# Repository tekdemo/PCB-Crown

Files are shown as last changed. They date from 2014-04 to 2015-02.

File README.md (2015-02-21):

PCB Crown
=========
A fun experiment in 3D circuits and wearables, designed as a gift to Laen. It was unveiled at the 2014 Maker Faire Bring-a-hack party. 

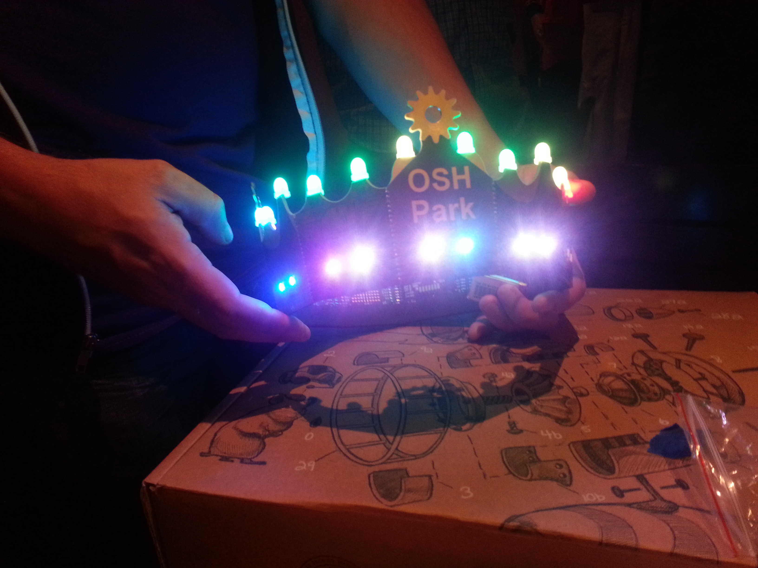
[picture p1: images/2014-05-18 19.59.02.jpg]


About The Crown
---------------
The structure of the crown is 11 different panels, held together via PCB Castellations and solder. The 11 panels are made from
5 different designs, and used 3 copies of the tall face plate, and 2 copies of each other design.

The electrical side of the crown is primarily configured to drive 2 individually addressable LED strings. There's a total of 44 RGB LEDs, configured as 2 strings of 22 each
The top uses [8mm Diffused LEDs](https://www.adafruit.com/products/1734), and the faces use [WS2812B SMD LEDs](https://www.adafruit.com/products/1655). These are 
powered by a [SMDuino module](https://code.google.com/p/smduino/), with optional buttons for whatever nefarious purpose seems desirable.

Each module also has a tiny circuit that acts as a SMD equivilent to a breadboard, suitable for future additions of accellerometers, gyros, or light sensors. 
Here's the crown glowing with the full might of the NeoPixels running Adafruit's test patterns. 

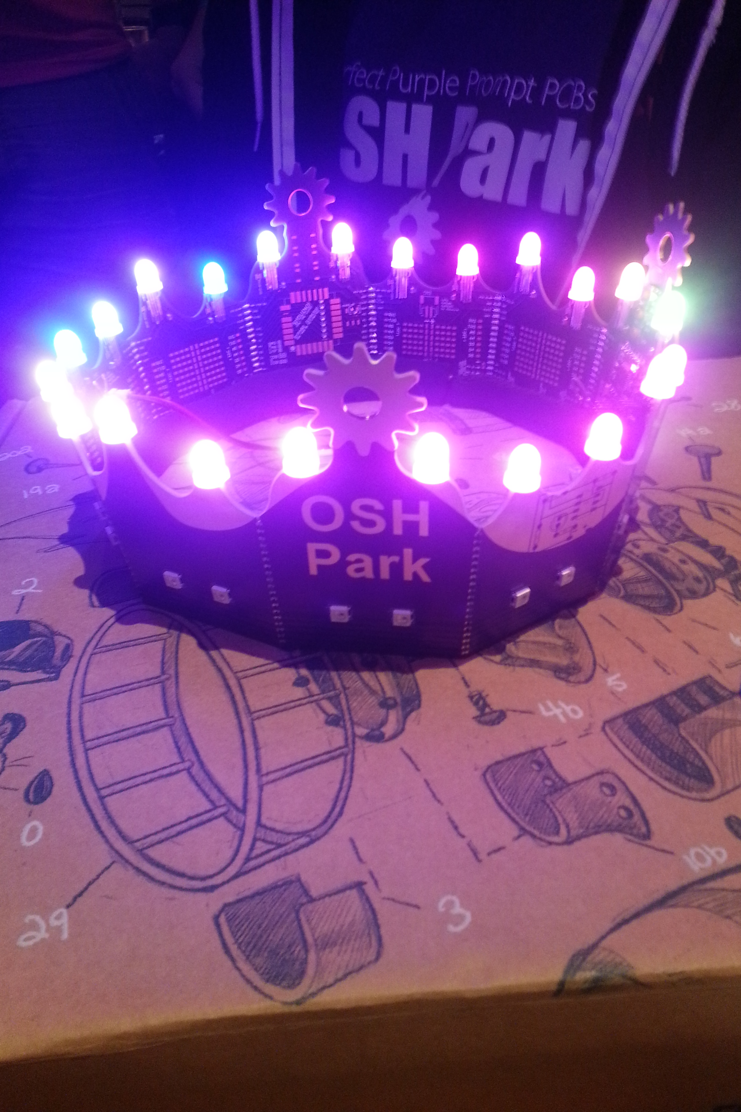
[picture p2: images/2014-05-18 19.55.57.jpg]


WARNING!
--------
This is being published as an demonstration and example project, not as a completed work suitable for replication. 
As an experimental design, this is _highly_ unlikely to work properly for you. The chosen board interconnects are incredibly fragile, and will often stop functioning
if bumped, jostled, or left alone quietly in a dark room. Several part footprints, due to artistic constraints, are maddening to assemble and virtually impossible to test effectively. 
No individual panel will work at all without the adjacent panel, requires at least 1 cut trace, and the LEDs will not work properly without at 
least half the design completed and working. 

Full documentation, build notes, and additional details are posted at [tekdemo.github.io/](https://tekdemo.github.io/pcb-crown/). This includes things not to do, as discovered
in the course of designing and building the crown.

License
--------
Files under `/images/` and the contents of the `gh-pages` branch are liscenced under [Creative Commons Attribution-ShareAlike 4.0](https://creativecommons.org/licenses/by-sa/4.0/)

All other files are released under the [MIT License](http://opensource.org/licenses/MIT).

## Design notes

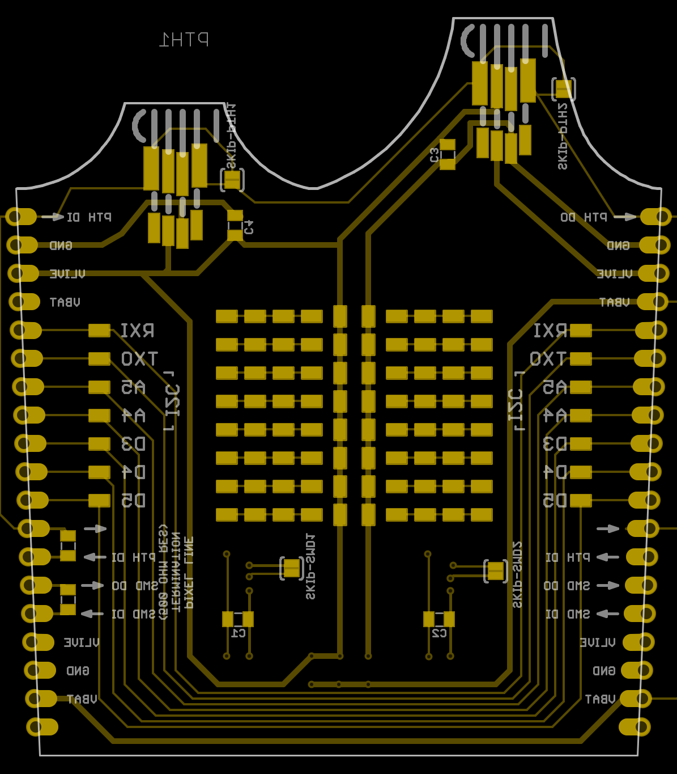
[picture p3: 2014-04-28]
gerber-previews/crown-C.board-bottom.png

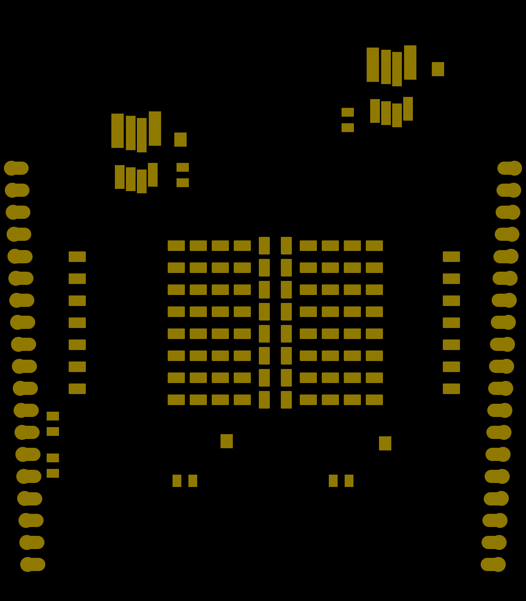
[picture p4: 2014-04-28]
gerber-previews/crown-C.bottomstopmask.png

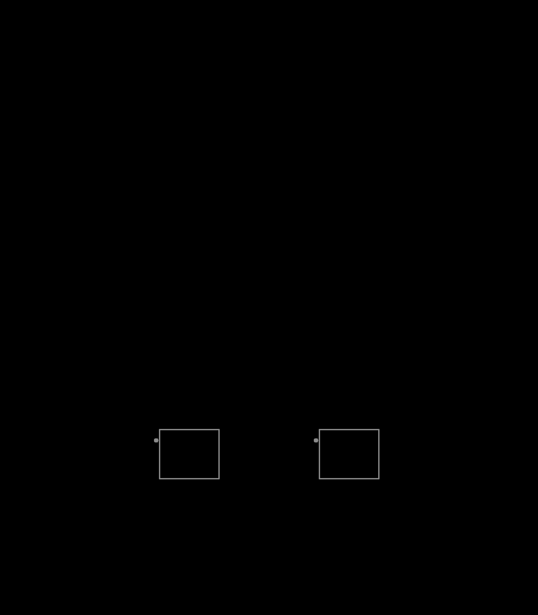
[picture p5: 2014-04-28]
gerber-previews/crown-F.topsilkscreen.png

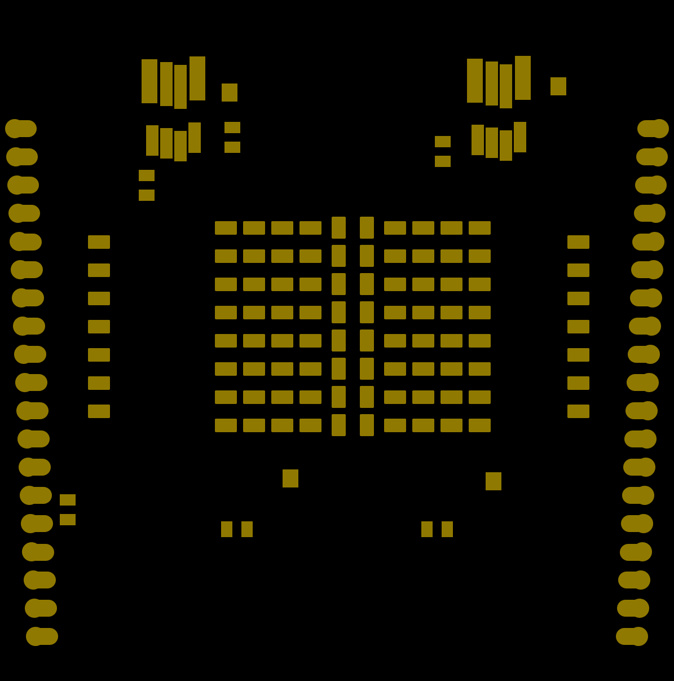
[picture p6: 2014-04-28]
gerber-previews/crown-E.bottomstopmask.diff.png

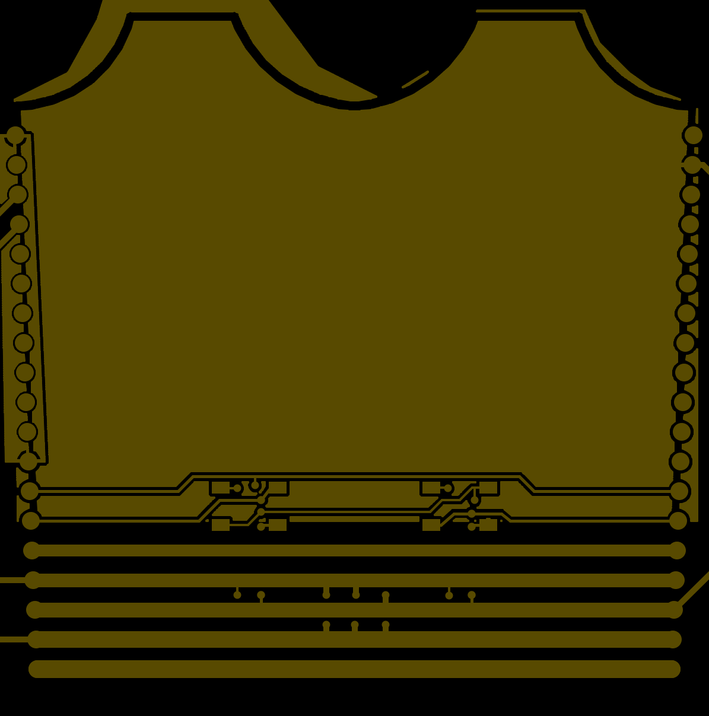
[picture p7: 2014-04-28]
gerber-previews/crown-E.toplayer.png

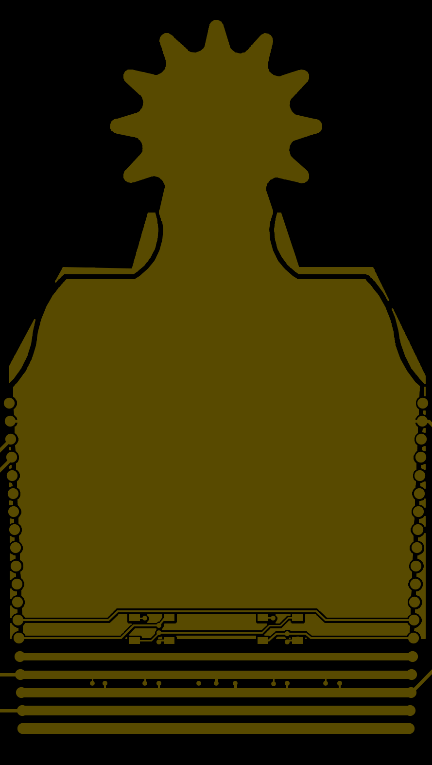
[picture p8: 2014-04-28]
gerber-previews/crown-face.toplayer.diff.png

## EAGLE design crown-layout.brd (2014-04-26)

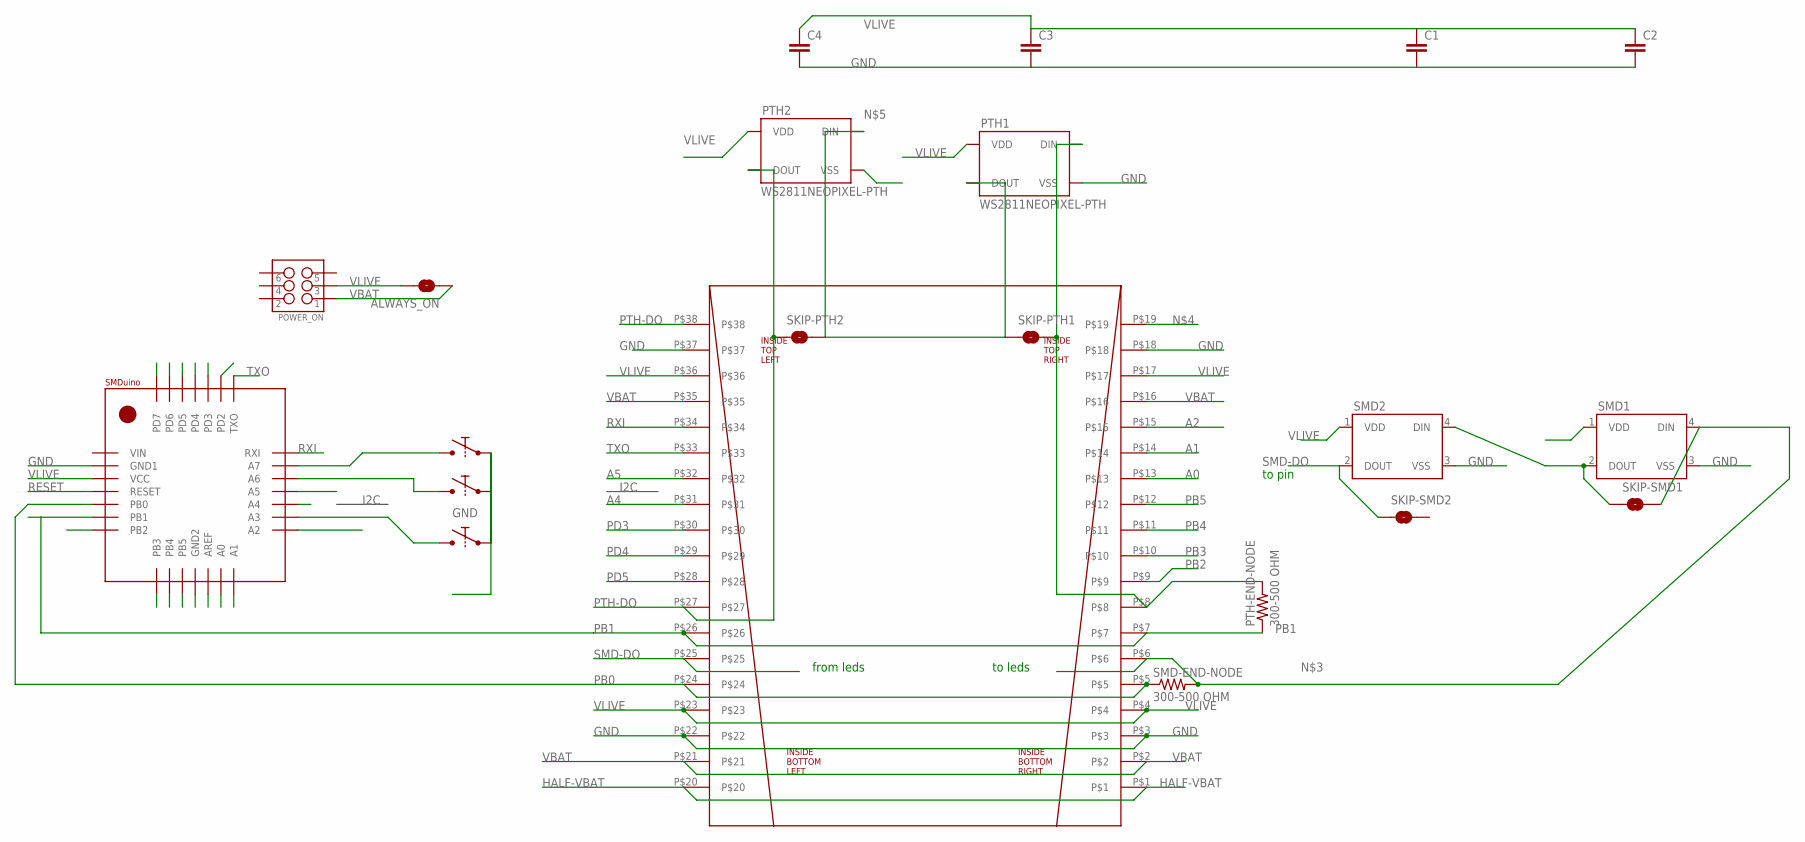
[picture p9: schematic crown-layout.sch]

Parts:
A6, A7: BUTTONSMD_BUTTON; SMD_BUTTON
ALWAYS_ON: SOLDERJUMPERNC2; SJ_2S-NOTRACE
C1, C2, C3, C4: CAP0805; 0805
D2: BUTTONSMD_BUTTON; SMD_BUTTON
POWER_ON: M03X2FEMALE_SMD; 2X3_SMD
PTH1, PTH2: WS2811NEOPIXEL-PTH; WS2811-PTH-FLAT
PTH-END-NODE: 300-500 OHM; 0805
SKIP-PTH1, SKIP-PTH2: SOLDERJUMPERNC2; SJ_2S-NOTRACE
SKIP-SMD1, SKIP-SMD2: SOLDERJUMPERNC2; SJ_2S-NOTRACE
SMD1, SMD2: WS2812B
SMD-END-NODE: 300-500 OHM; 0805
U$1: SMDUINO
U$2: CROWNSTANDARD; CROWN

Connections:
A0: U$1.A0, U$2.P$13
A1: U$1.A1, U$2.P$14
A2: U$1.A2, U$2.P$15
A3: A6.P$1, A6.P$2, U$1.A3
A4: U$1.A4, U$2.P$31
A5: U$1.A5, U$2.P$32
A6: A7.P$1, A7.P$2, U$1.A6
A7: D2.P$1, D2.P$2, U$1.A7
GND: A6.P$3, A6.P$4, A7.P$3, A7.P$4, C1.2, C2.2, C3.2, C4.2, D2.P$3, D2.P$4, PTH1.P$2 (VSS), PTH1.P$6 (VSS), PTH2.P$2 (VSS), PTH2.P$6 (VSS), SMD1.3 (VSS), SMD2.3 (VSS), U$1.GND1, U$2.P$3, U$2.P$18, U$2.P$22, U$2.P$37
HALF-VBAT: U$2.P$1, U$2.P$20
unnamed: SKIP-SMD1.2, SMD1.4 (DIN), SMD-END-NODE.2, U$2.P$6
unnamed: PTH1.P$4 (DIN), PTH1.P$8 (DIN), PTH-END-NODE.2, SKIP-PTH1.2, U$2.P$8, U$2.P$19
unnamed: PTH1.P$1 (DOUT), PTH1.P$5 (DOUT), PTH2.P$4 (DIN), PTH2.P$8 (DIN), SKIP-PTH1.1, SKIP-PTH2.2
unnamed: SKIP-SMD1.1, SMD1.2 (DOUT), SMD2.4 (DIN)
PB0: SMD-END-NODE.1, U$1.PB0, U$2.P$5, U$2.P$24
PB1: PTH-END-NODE.1, U$1.PB1, U$2.P$7, U$2.P$26
PB2: U$1.PB2, U$2.P$9
PB3: U$1.PB3, U$2.P$10
PB4: U$1.PB4, U$2.P$11
PB5: U$2.P$12
PD2: U$1.PD2
PD3: U$1.PD3, U$2.P$30
PD4: U$1.PD4, U$2.P$29
PD5: U$1.PD5, U$2.P$28
PD6: U$1.PD6
PD7: U$1.PD7
PTH-DO: PTH2.P$1 (DOUT), PTH2.P$5 (DOUT), SKIP-PTH2.1, U$2.P$27, U$2.P$38
RESET: U$1.RESET
RXI: U$1.RXI, U$2.P$34
SMD-DO: SKIP-SMD2.1, SMD2.2 (DOUT), U$2.P$25
TXO: U$1.TXO, U$2.P$33
VBAT: ALWAYS_ON.1, POWER_ON.1, U$2.P$2, U$2.P$16, U$2.P$21, U$2.P$35
VLIVE: ALWAYS_ON.2, C1.1, C2.1, C3.1, C4.1, POWER_ON.3, PTH1.P$3 (VDD), PTH1.P$7 (VDD), PTH2.P$3 (VDD), PTH2.P$7 (VDD), SMD1.1 (VDD), SMD2.1 (VDD), U$1.VCC, U$2.P$4, U$2.P$17, U$2.P$23, U$2.P$36

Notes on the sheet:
from leds
to pin
to leds

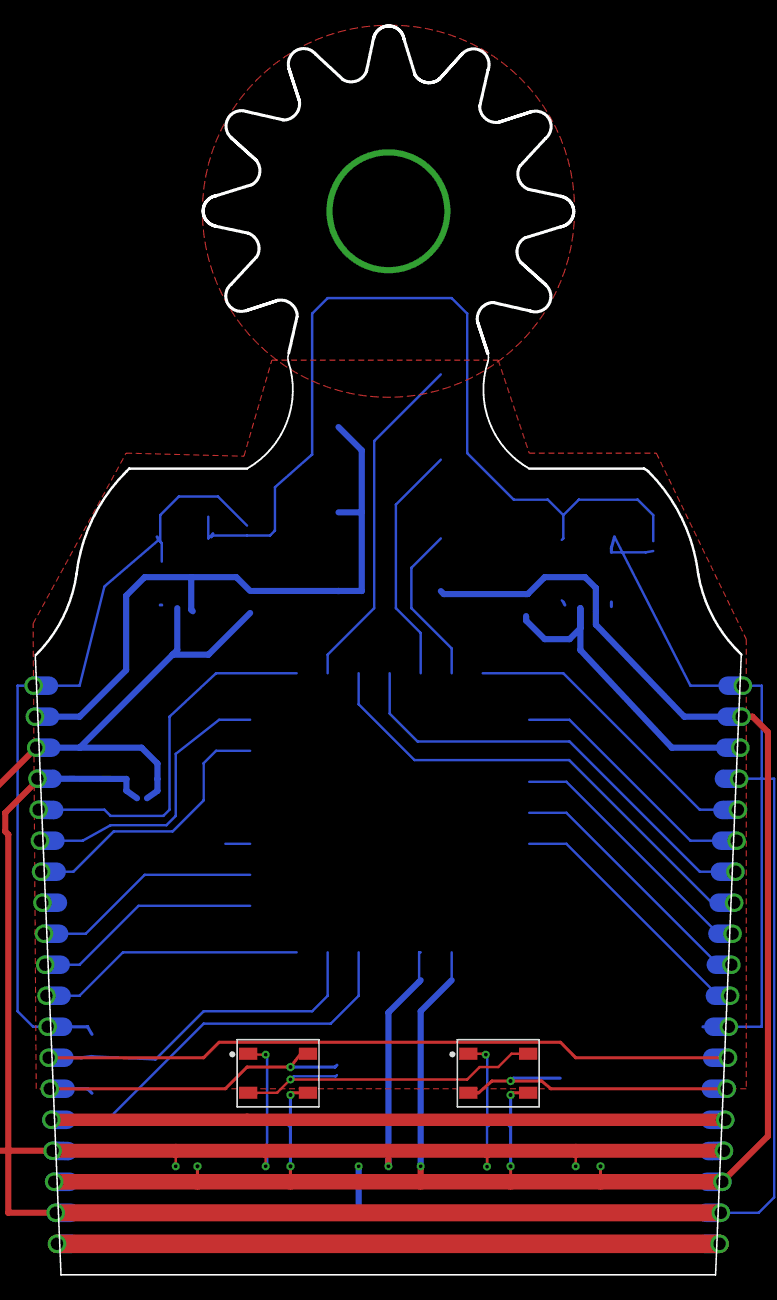
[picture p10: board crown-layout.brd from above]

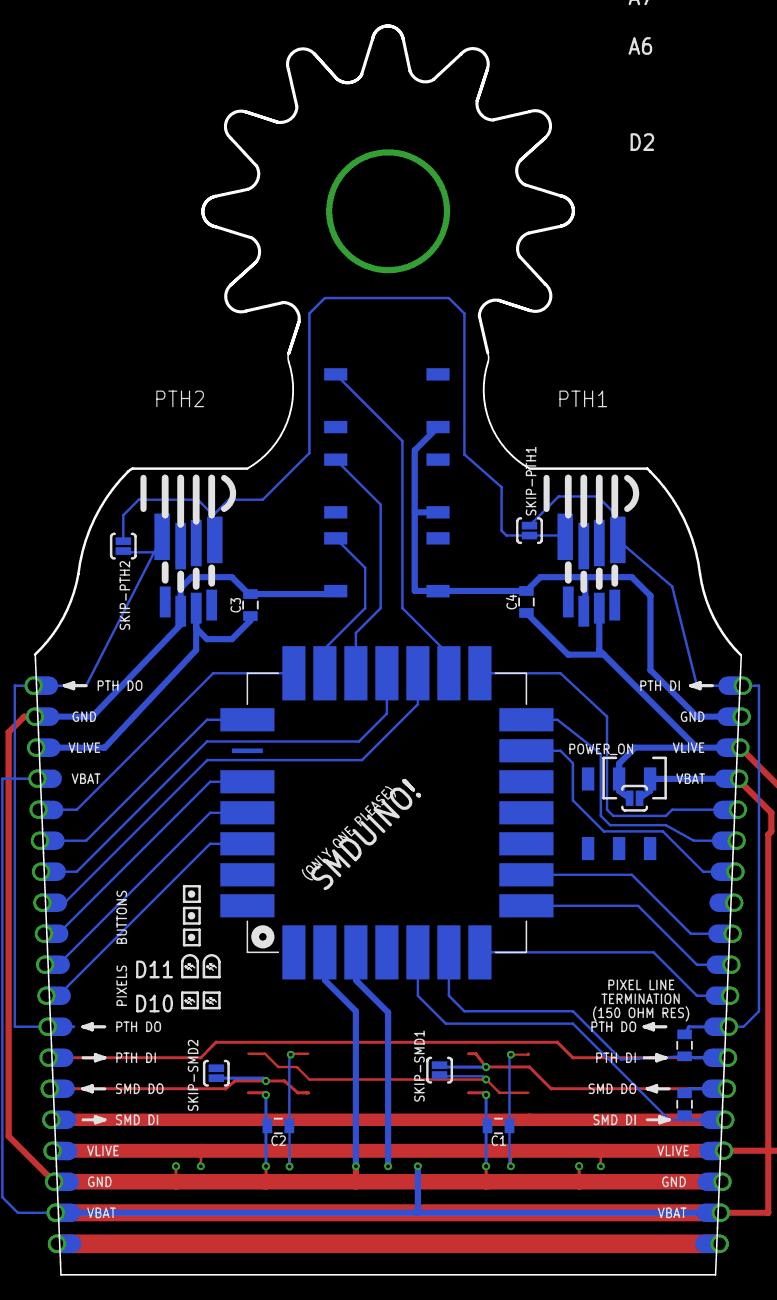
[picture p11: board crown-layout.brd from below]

Board: 2 copper layers, 57.9 x 102.3 mm, 21 parts (18 on the bottom side), 28 nets.

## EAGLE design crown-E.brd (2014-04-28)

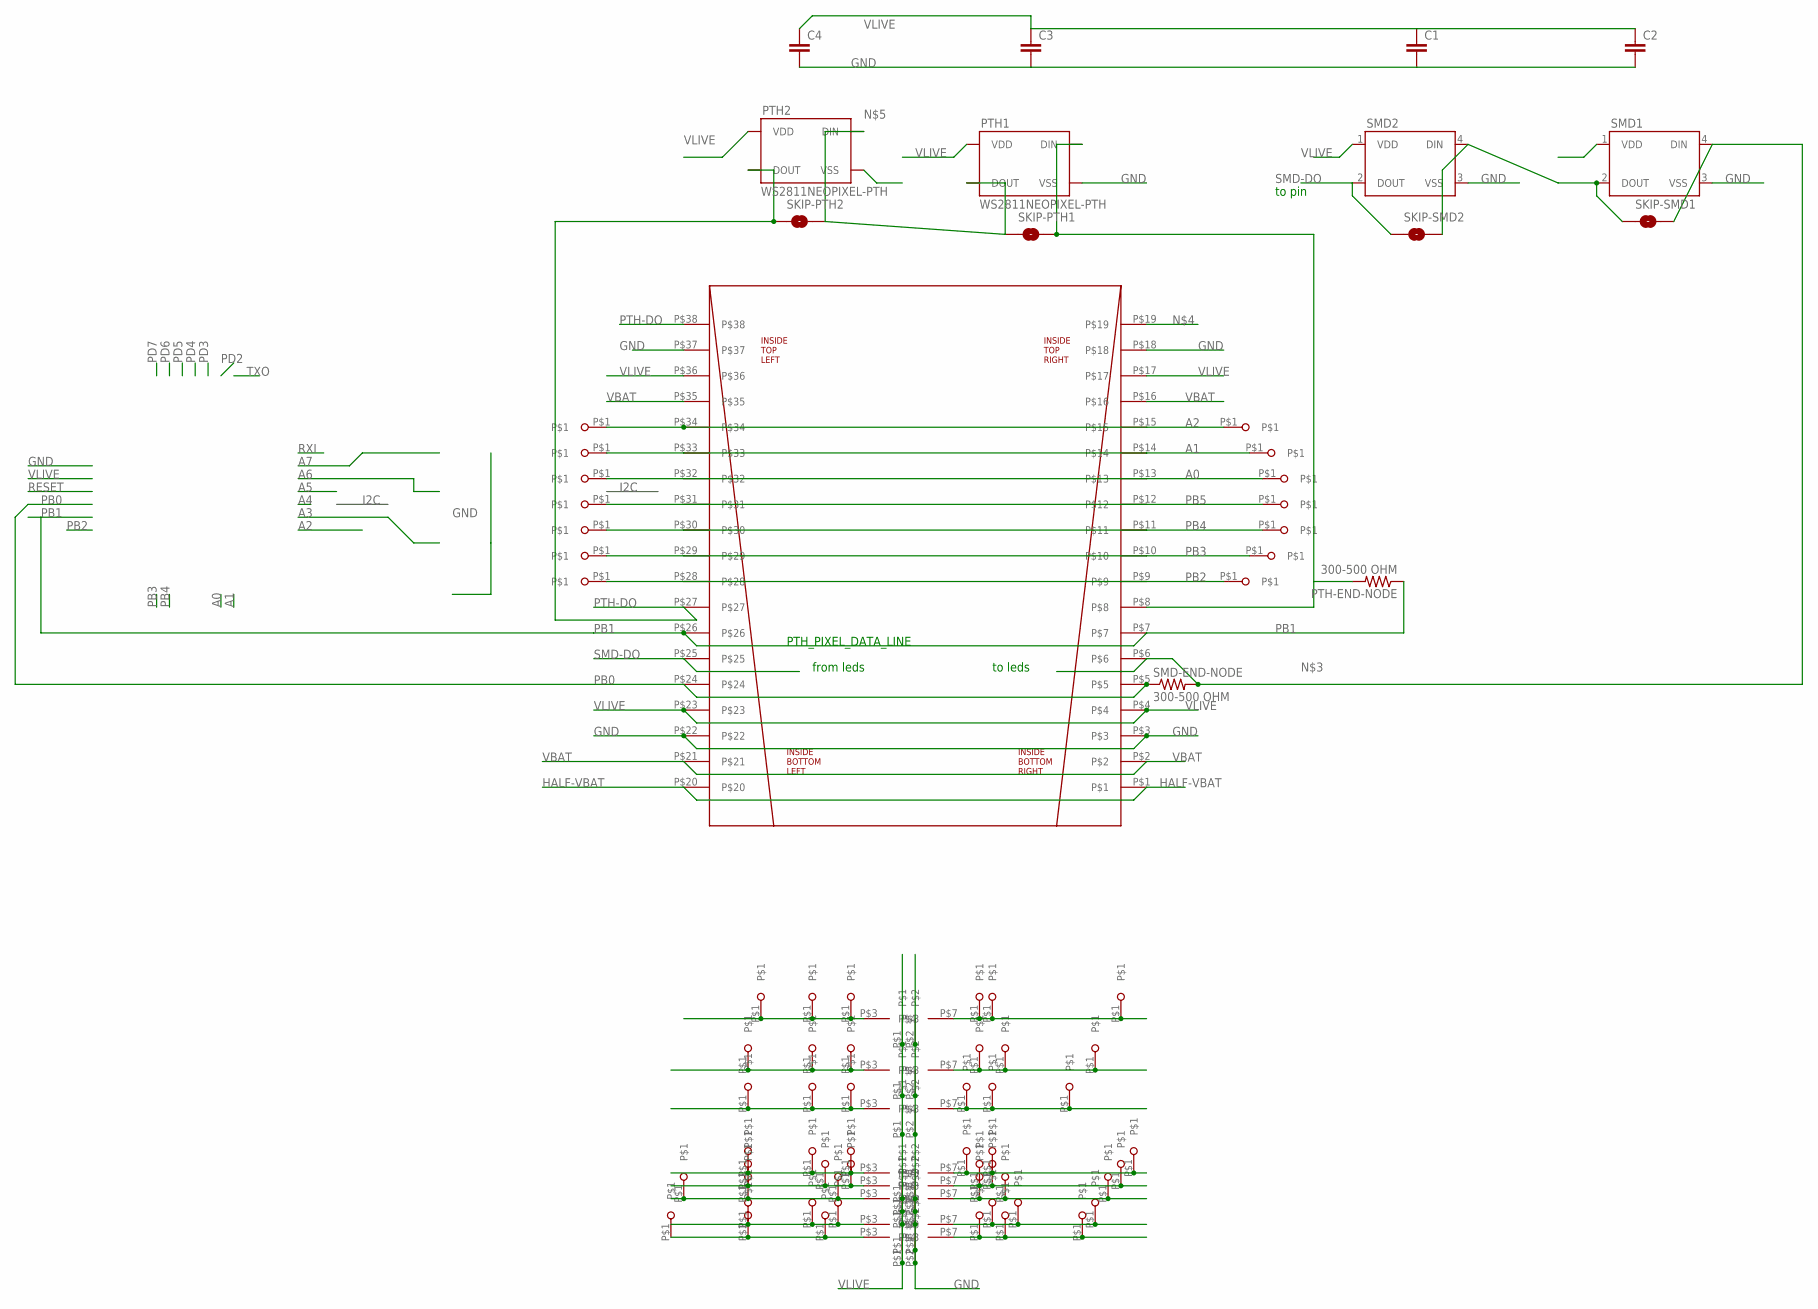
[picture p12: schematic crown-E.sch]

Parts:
C1, C2, C3, C4: CAP0805; 0805
PTH1, PTH2: WS2811NEOPIXEL-PTH; WS2811-PTH-FLAT
PTH-END-NODE: 300-500 OHM; 0805
SKIP-PTH1, SKIP-PTH2: SOLDERJUMPERNC2; SJ_2S-NOTRACE
SKIP-SMD1, SKIP-SMD2: SOLDERJUMPERNC2; SJ_2S-NOTRACE
SMD1, SMD2: WS2812B
SMD-END-NODE: 300-500 OHM; 0805
U$1, U$3, U$4, U$5, U$6, U$7, U$8, U$9: SMD_BREADBOARD; SMD_BREADBOARD_4X
U$2: CROWNSTANDARD; CROWN
U$10, U$11, U$12, U$13, U$14, U$15, U$16, U$17, U$18, U$19, U$20, U$21, U$22, U$23, U$24, U$25, U$26, U$27, U$28, U$29, U$30, U$31, U$32, U$33, U$34, U$35, U$36, U$37, U$38, U$39, U$40, U$41, U$42, U$43, U$44, U$45, U$46, U$47, U$48, U$49, U$50, U$51, U$52, U$53, U$54, U$55, U$56, U$57, U$58, U$59, U$60, U$61, U$62, U$63, U$64, U$65, U$66, U$67, U$68, U$69, U$70, U$71: SMD_PAD; SMD_BREADBOARD_PAD

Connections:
A0: U$2.P$13, U$2.P$32, U$44.P$1, U$55.P$1
A1: U$2.P$14, U$2.P$33, U$43.P$1, U$56.P$1
A2: U$2.P$15, U$2.P$34, U$42.P$1, U$58.P$1
GND: C1.2, C2.2, C3.2, C4.2, PTH1.P$2 (VSS), PTH1.P$6 (VSS), PTH2.P$2 (VSS), PTH2.P$6 (VSS), SMD1.3 (VSS), SMD2.3 (VSS), U$1.P$2, U$2.P$3, U$2.P$18, U$2.P$22, U$2.P$37, U$3.P$2, U$4.P$2, U$5.P$2, U$6.P$2, U$7.P$2, U$8.P$2, U$9.P$2
HALF-VBAT: U$2.P$1, U$2.P$20
unnamed: U$1.P$3, U$24.P$1, U$25.P$1, U$63.P$1
unnamed: SKIP-SMD1.2, SMD1.4 (DIN), SMD-END-NODE.2, U$2.P$6
unnamed: PTH1.P$4 (DIN), PTH1.P$8 (DIN), PTH-END-NODE.2, SKIP-PTH1.2, U$2.P$8, U$2.P$19
unnamed: PTH1.P$1 (DOUT), PTH1.P$5 (DOUT), PTH2.P$4 (DIN), PTH2.P$8 (DIN), SKIP-PTH1.1, SKIP-PTH2.2
unnamed: U$3.P$3, U$22.P$1, U$23.P$1, U$62.P$1
unnamed: U$9.P$3, U$20.P$1, U$21.P$1, U$61.P$1
unnamed: U$8.P$3, U$18.P$1, U$19.P$1, U$60.P$1
unnamed: U$4.P$3, U$16.P$1, U$17.P$1, U$59.P$1
unnamed: SKIP-SMD1.1, SKIP-SMD2.2, SMD1.2 (DOUT), SMD2.4 (DIN)
unnamed: U$5.P$3, U$14.P$1, U$15.P$1, U$57.P$1
unnamed: U$6.P$3, U$12.P$1, U$13.P$1, U$50.P$1
unnamed: U$7.P$3, U$10.P$1, U$11.P$1, U$49.P$1
unnamed: U$7.P$7, U$40.P$1, U$41.P$1, U$71.P$1
unnamed: U$6.P$7, U$38.P$1, U$39.P$1, U$70.P$1
unnamed: U$5.P$7, U$36.P$1, U$37.P$1, U$69.P$1
unnamed: U$4.P$7, U$34.P$1, U$35.P$1, U$68.P$1
unnamed: U$8.P$7, U$32.P$1, U$33.P$1, U$67.P$1
unnamed: U$9.P$7, U$30.P$1, U$31.P$1, U$66.P$1
unnamed: U$3.P$7, U$28.P$1, U$29.P$1, U$65.P$1
unnamed: U$1.P$7, U$26.P$1, U$27.P$1, U$64.P$1
PB0: SMD-END-NODE.1, U$2.P$5, U$2.P$24
PB1: PTH-END-NODE.1, U$2.P$7, U$2.P$26
PB2: U$2.P$9, U$2.P$28, U$48.P$1, U$51.P$1
PB3: U$2.P$10, U$2.P$29, U$47.P$1, U$52.P$1
PB4: U$2.P$11, U$2.P$30, U$46.P$1, U$53.P$1
PB5: U$2.P$12, U$2.P$31, U$45.P$1, U$54.P$1
PTH-DO: PTH2.P$1 (DOUT), PTH2.P$5 (DOUT), SKIP-PTH2.1, U$2.P$27, U$2.P$38
SMD-DO: SKIP-SMD2.1, SMD2.2 (DOUT), U$2.P$25
VBAT: U$2.P$2, U$2.P$16, U$2.P$21, U$2.P$35
VLIVE: C1.1, C2.1, C3.1, C4.1, PTH1.P$3 (VDD), PTH1.P$7 (VDD), PTH2.P$3 (VDD), PTH2.P$7 (VDD), SMD1.1 (VDD), SMD2.1 (VDD), U$1.P$1, U$2.P$4, U$2.P$17, U$2.P$23, U$2.P$36, U$3.P$1, U$4.P$1, U$5.P$1, U$6.P$1, U$7.P$1, U$8.P$1, U$9.P$1

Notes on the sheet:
from leds
to pin
to leds
PTH_PIXEL_DATA_LINE

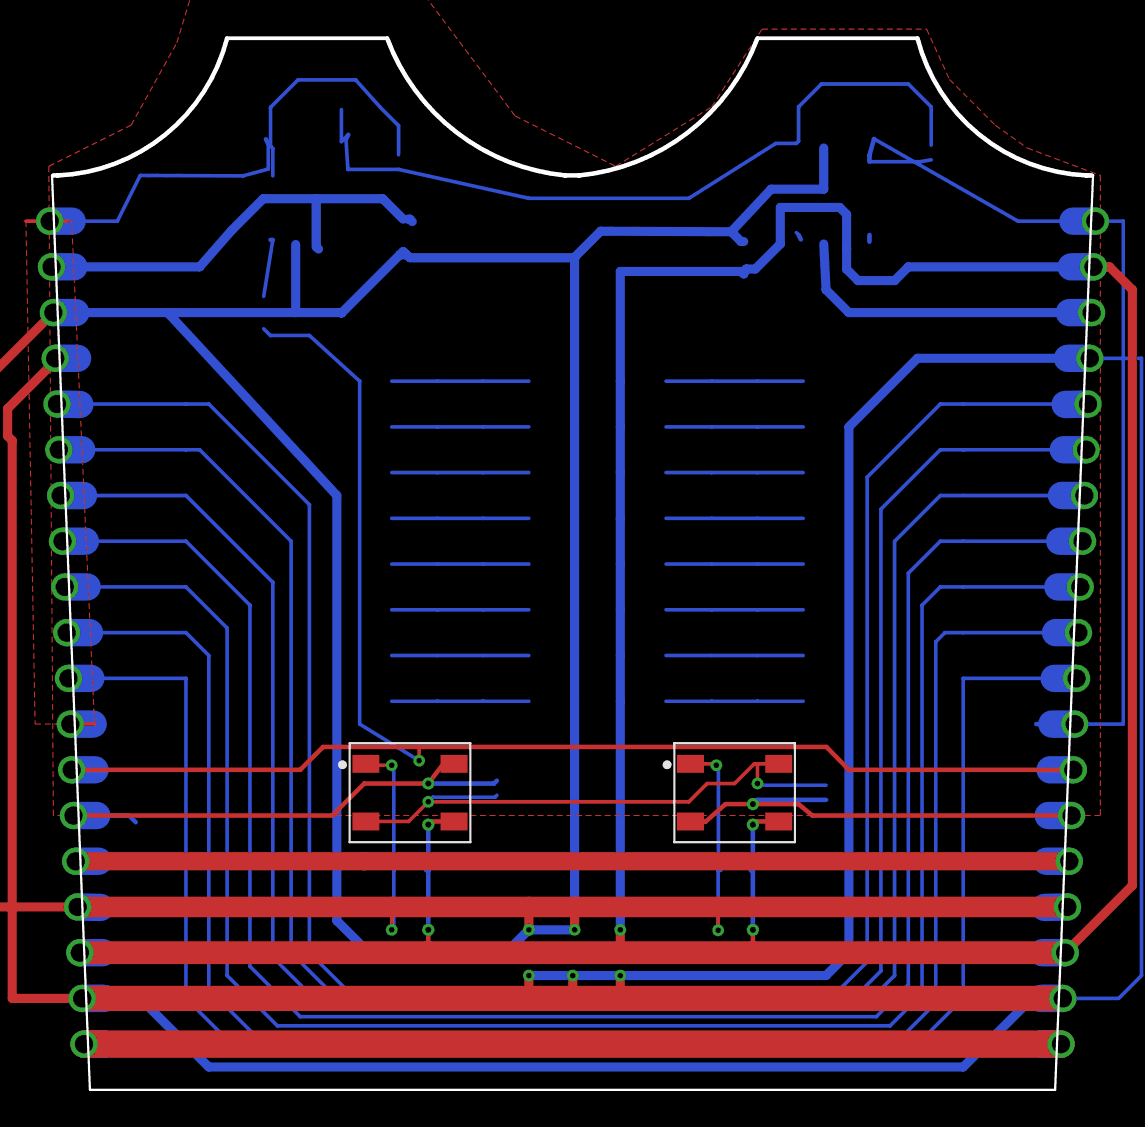
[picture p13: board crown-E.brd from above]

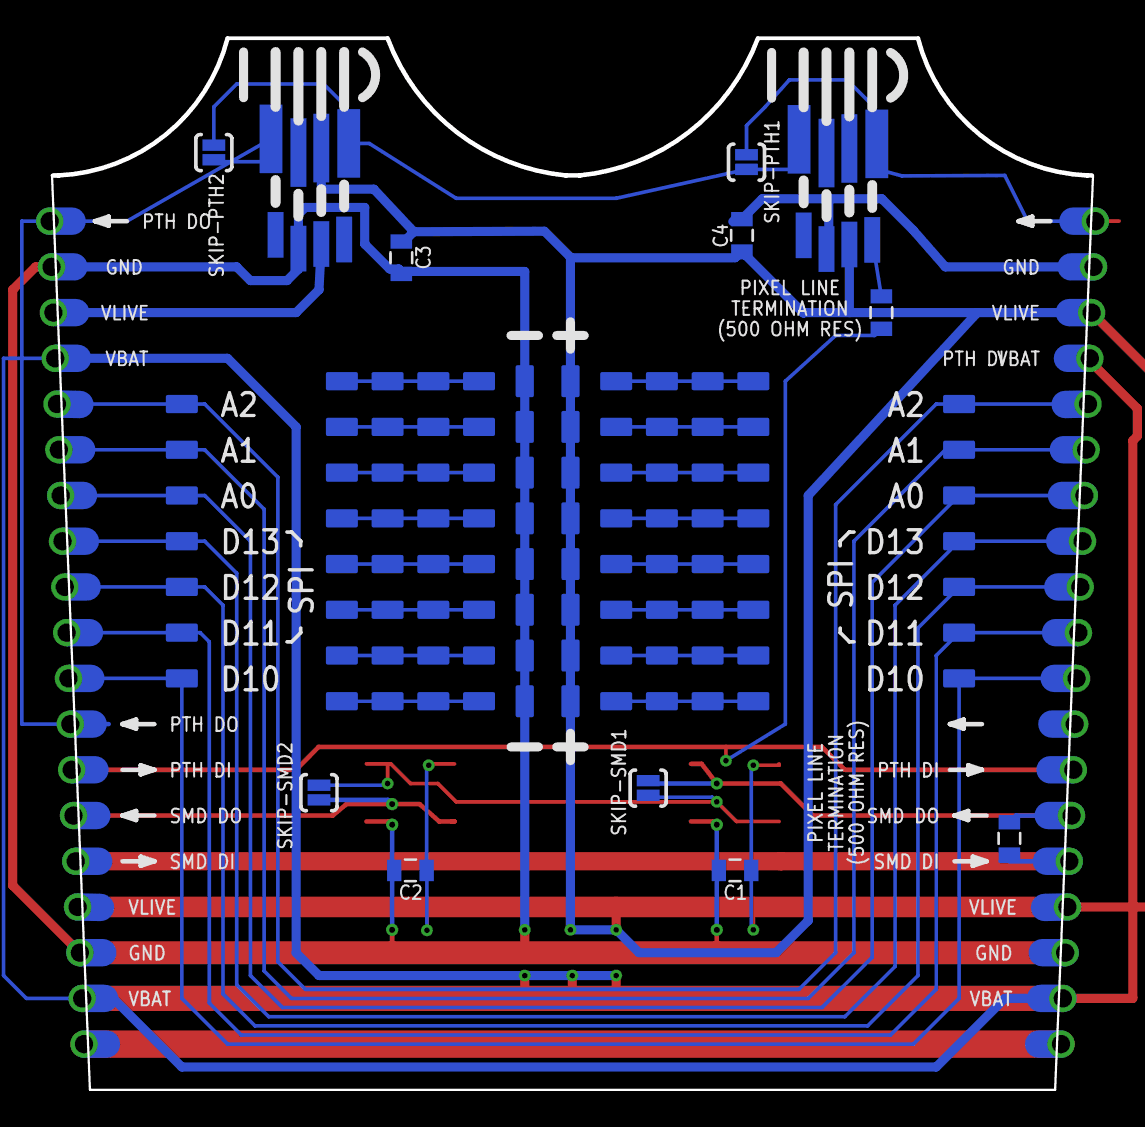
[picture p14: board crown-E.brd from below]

Board: 2 copper layers, 57.8 x 58.4 mm, 85 parts (82 on the bottom side), 35 nets.

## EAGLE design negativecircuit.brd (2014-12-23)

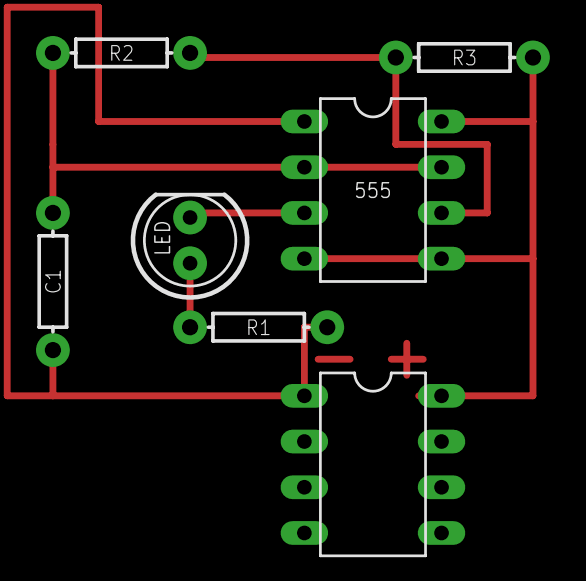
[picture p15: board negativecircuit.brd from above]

Board: 2 copper layers, 7 parts (0 on the bottom side), 4 nets.

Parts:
555: DIL08
C1: AXIAL-0.3EZ
E$5: DIL08
LED: LED5MM
R1, R2, R3: AXIAL-0.3EZ

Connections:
S$2: 555.3, LED.K
S$4: 555.2, 555.7
S$8: 555.4, 555.5, 555.8
S$9: 555.1, LED.A, R1.P$1, R1.P$2

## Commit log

2014-04-26 Initial commit after completing crown face
    [crown-C.brd, crown-C.sch, crown-face.brd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]
2014-04-26 Fixed outline to only show crown
    [crown-face.brd]
2014-04-26 Made B board, looks a bit funky on the routing.
    [crown-B.brd, crown-B.sch, crown-layout.brd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]
2014-04-26 Fixed it! :D
    [crown-face.brd, crown-face.sch]
2014-04-27 Mostly routed! :D
    [crown-C.brd, crown-C.sch]
2014-04-28 Fixed disconnected routes on all panels
    added bypass jumpers across face panel
    added vbat and vlive jumpers from top to bottom
    corrected accidental mirroring
    yay
    [crown-F.brd, crown-F.sch]
2014-04-28 Added B plate, which holds battery (best for lipo)
    [crown-B.brd, crown-B.sch]
2014-04-28 fixed dimension issue
    [crown-B.brd]
2014-04-28 Just cleanup stuff
    [crown-C.brd, crown-F.brd, crown-face.brd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]
2014-04-28 Added final panel! whooo!
    [crown-E.brd, crown-E.sch]
2014-04-28 Fixed top stop layer
    [crown-E.brd]
2014-04-28 tidied up a little bit
    [crown-B.brd, crown-C.brd, crown-E.brd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]
2014-04-28 fixed dimension layer
    [crown-C.brd]
2014-04-28 Deleted cruft
    [crown-layout.brd, crown-layout.sch]
2014-04-28 Cleanup of stop mask layers
    [crown-B.brd, crown-C.brd, crown-E.brd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]
2014-04-28 forgot a connection on skip-smd bits
    [crown-B.brd, crown-B.sch, crown-C.brd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]
2014-04-28 fixed incorrect resistor value
    [crown-B.brd, crown-C.brd, crown-E.brd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]
2014-04-28 noticed it's WAY THE FUCK WRONG GAAAAH
    [crown-E.brd]
2014-04-28 Fixed stupid outline mistake on panel E
    [crown-B.brd, crown-E.brd, negativecircuit.brd]
2014-04-28 forgot the measures
    [crown-E.brd]
2014-12-23 Prep final project files for publication
    [crown-layout.brd, crown-layout.sch, negativecircuit.brd]

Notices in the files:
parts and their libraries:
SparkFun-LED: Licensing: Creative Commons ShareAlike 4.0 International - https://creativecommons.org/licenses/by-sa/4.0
